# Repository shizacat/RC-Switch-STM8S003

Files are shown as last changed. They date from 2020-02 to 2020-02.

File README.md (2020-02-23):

# Description

Reacts to switching the joystick stick switch.

## Principle of work

The input receives a PWM signal from an RC receiver. For different stick positions there will be different duty cycle. By measuring its duration, you can determine the position of the stick and send a signal to the MC output.

# Hardware

Since my option was needed to turn on the LED backlight, I do not use external power and a powerful transistor. I also needed only one position.

# Firwmware

SDCC is used for compilation. You also need STM8S_SPL from ST - a library for working with peripherals.

## How to flash

I use stm8flash for flash.

First of all, you need to configure Option bytes for hardware. For capturing, the 1st channel of the 1st timer is used (Channel 1 TIM1).

```bash
echo -ne '\x00\x00\xff\x01\xfe\x00\xff\x00\xff\x00\xff' > opt.bin
stm8flash -c stlinkv2 -p stm8s103f3 -s opt -w opt.bin
```

This line activates alternative functions of the leg we need: Port C5 alternate function = TIM2_CH1; port C6 alternate function =TIM1_CH1; port C7 alternate function = TIM1_CH2.

Then we are already flashing the firmware itself (firmware.bin). Here you can already use: make upload, or manually download stm8flash.

```bash
./stm8flash -c stlinkv2 -p stm8s003f3 -w firmware.ihx
```

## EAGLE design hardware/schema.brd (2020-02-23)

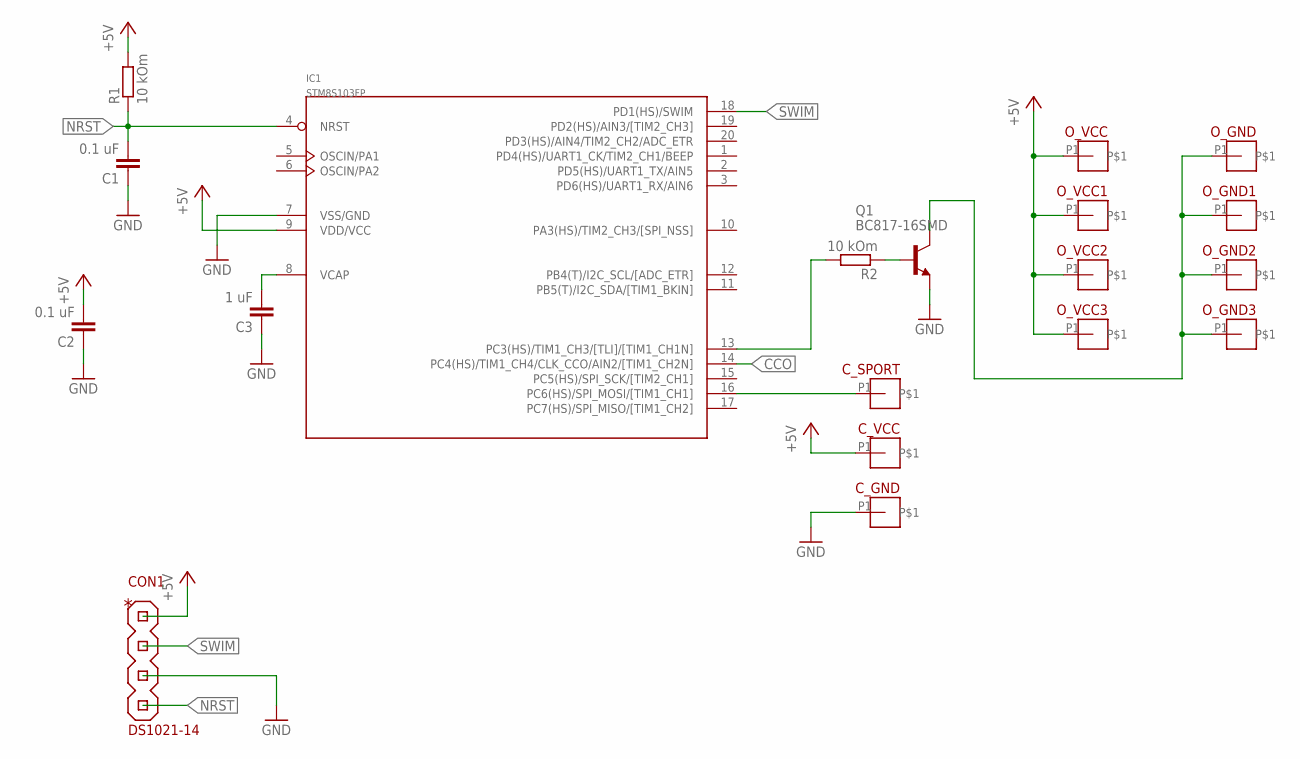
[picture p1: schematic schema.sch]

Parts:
C1, C2: 0.1 uF; C0603
C3: 1 uF; C0603
CON1: DS1021-14; DS1021-1*4
C_GND: PAD1_0.8
C_SPORT: PAD1_0.8
C_VCC: PAD1_0.8
IC1: STM8S103FP; TSSOP20
O_GND, O_GND1, O_GND2, O_GND3: PAD1_0.8
O_VCC, O_VCC1, O_VCC2, O_VCC3: PAD1_0.8
Q1: BC817-16SMD; SOT23-BEC
R1, R2: 10 kOm; R0603

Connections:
+5V: C2.2, CON1.P1, C_VCC.P1, IC1.9 (VDD/VCC), O_VCC.P1, O_VCC1.P1, O_VCC2.P1, O_VCC3.P1, R1.2
CCO: IC1.14 (PC4(HS)/TIM1_CH4/CLK_CCO/AIN2/[TIM1_CH2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)
GND: C1.1, C2.1, C3.1, CON1.P3, C_GND.P1, IC1.7 (VSS/GND), Q1.E
unnamed: C_SPORT.P1, IC1.16 (PC6(HS)/SPI_MOSI/[TIM1_CH1])
unnamed: C3.2, IC1.8 (VCAP)
unnamed: O_GND.P1, O_GND1.P1, O_GND2.P1, O_GND3.P1, Q1.C
unnamed: IC1.13 (PC3(HS)/TIM1_CH3/[TLI]/[TIM1_CH1N]), R2.2
unnamed: Q1.B, R2.1
NRST: C1.2, CON1.P4, IC1.4 (NRST), R1.1
SWIM: CON1.P2, IC1.18 (PD1(HS)/SWIM)

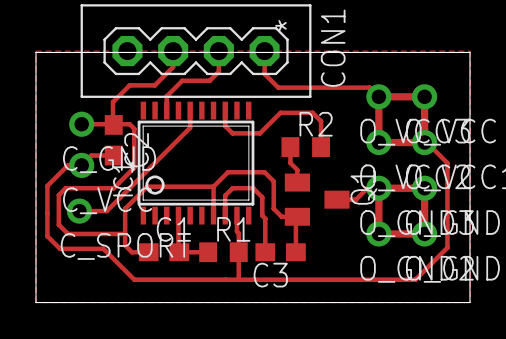
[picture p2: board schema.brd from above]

Board: 2 copper layers, 24.1 x 13.9 mm, 19 parts (0 on the bottom side), 9 nets.

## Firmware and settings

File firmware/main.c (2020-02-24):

/**
  ******************************************************************************
  * @file     RC-Switch\main.c
  * @author   
  * @version  
  * @date     
  * @brief    
  ******************************************************************************
  * @attention
  *
  ******************************************************************************
  */ 

/* Includes ------------------------------------------------------------------*/
#include "stm8s.h"

/* Private typedef -----------------------------------------------------------*/
/* Private define ------------------------------------------------------------*/
/* Private macro -------------------------------------------------------------*/
/* Private variables ---------------------------------------------------------*/
uint16_t ICValue1 =0, ICValue2 =0;
uint8_t state =0;

/* Private function prototypes -----------------------------------------------*/
static void TIM1_Config(void);
static void GPIO_Config(void);
static void CLK_Config(void);

/* Private functions ---------------------------------------------------------*/
/* Public functions ----------------------------------------------------------*/

/**
  * @brief  Main program.
  * @param  None
  * @retval None
  */
void main(void)
{

  /* GPIO CONFIG ----------------------------------------------- */
  GPIO_Config();

  CLK_Config();

  /* TIM1 configuration -----------------------------------------*/
  TIM1_Config();
    
  /* Insert a break point here */
  while (1)
  {
    if (TIM1_GetFlagStatus(TIM1_FLAG_CC1) == SET) {
      if(state == FALSE)          {
          ICValue1 = TIM1_GetCapture1();
          TIM1_ICInit(
            TIM1_CHANNEL_1, TIM1_ICPOLARITY_FALLING, TIM1_ICSELECTION_DIRECTTI,
            TIM1_ICPSC_DIV1, 0x0
          );
      }
      else {
          ICValue2 = TIM1_GetCapture1();
          TIM1_ICInit(
            TIM1_CHANNEL_1, TIM1_ICPOLARITY_RISING, TIM1_ICSELECTION_DIRECTTI,
            TIM1_ICPSC_DIV1, 0x0
          );
          // Check threshold
          if ((ICValue2 - ICValue1) >= 80) {
            GPIO_WriteHigh(GPIOC, GPIO_PIN_3);
          } else {
            GPIO_WriteLow(GPIOC, GPIO_PIN_3);
          };
      }
      state = ~state;
      TIM1_ClearFlag(TIM1_FLAG_CC1);
    }
  }
}

/**
  * @brief  Configure ports
  * @param  None
  * @retval None
  */
static void GPIO_Config(void){
  /* Connect LSI to COO pin*/
  GPIO_Init(GPIOC, GPIO_PIN_4, GPIO_MODE_OUT_PP_LOW_FAST);
  CLK_CCOConfig(CLK_OUTPUT_LSI);
  CLK_CCOCmd(ENABLE);

  // Pin to transistor key
  GPIO_Init(GPIOC, GPIO_PIN_3, GPIO_MODE_OUT_PP_LOW_FAST);
  // Pin input signal
  // GPIO_Init(GPIOC, GPIO_PIN_6, GPIO_MODE_IN_PU_NO_IT);
}

/**
  * @brief  Switch to LSI as system clock source.
            System clock prescaler: 1
  * @param  None
  * @retval None
  */
static void CLK_Config(void){
  // CLK_DeInit();

  CLK_LSICmd(ENABLE);
  CLK_SYSCLKConfig(CLK_PRESCALER_CPUDIV1);
  CLK_ClockSwitchConfig(
    CLK_SWITCHMODE_AUTO,
    CLK_SOURCE_LSI, 
    DISABLE,
    CLK_CURRENTCLOCKSTATE_DISABLE
  );

  // Configure periphery
  CLK_PeripheralClockConfig(CLK_PERIPHERAL_I2C, DISABLE);
  CLK_PeripheralClockConfig(CLK_PERIPHERAL_SPI, DISABLE);
  CLK_PeripheralClockConfig(CLK_PERIPHERAL_UART1, DISABLE);
  CLK_PeripheralClockConfig(CLK_PERIPHERAL_UART2, DISABLE);
  CLK_PeripheralClockConfig(CLK_PERIPHERAL_TIMER4, DISABLE);
  CLK_PeripheralClockConfig(CLK_PERIPHERAL_TIMER2, DISABLE);
  CLK_PeripheralClockConfig(CLK_PERIPHERAL_TIMER3, DISABLE);
  CLK_PeripheralClockConfig(CLK_PERIPHERAL_AWU, DISABLE);
  CLK_PeripheralClockConfig(CLK_PERIPHERAL_ADC, DISABLE);
  CLK_PeripheralClockConfig(CLK_PERIPHERAL_CAN, DISABLE);

  CLK_PeripheralClockConfig(CLK_PERIPHERAL_TIMER1, ENABLE);
}

/**
  * @brief  Configure TIM1 to to capture the internal clock source (LSI)
  * @param  None
  * @retval None
  */
static void TIM1_Config(void)
{
  TIM1_DeInit();

  TIM1_TimeBaseInit(27, TIM1_COUNTERMODE_UP, 0xFFFF, 0);
  TIM1_ICInit(
    TIM1_CHANNEL_1, TIM1_ICPOLARITY_FALLING, TIM1_ICSELECTION_DIRECTTI,
    TIM1_ICPSC_DIV1, 0x0
  );
  
  // Enable TIM1
  TIM1_Cmd(ENABLE);
}

#ifdef USE_FULL_ASSERT

/**
  * @brief  Reports the name of the source file and the source line number
  *   where the assert_param error has occurred.
  * @param file: pointer to the source file name
  * @param line: assert_param error line source number
  * @retval None
  */
void assert_failed(uint8_t* file, uint32_t line)
{ 
  /* User can add his own implementation to report the file name and line number,
     ex: printf("Wrong parameters value: file %s on line %d\r\n", file, line) */

  /* Infinite loop */
  while (1)
  {
  }
}
#endif

/************************ END OF FILE ****/

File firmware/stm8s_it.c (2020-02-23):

/**
  ******************************************************************************
  * @file     stm8s_it.c
  * @author   MCD Application Team
  * @version  V2.2.0
  * @date     30-September-2014
  * @brief    Main Interrupt Service Routines.
  ******************************************************************************
  * @attention
  *
  * <h2><center>&copy; COPYRIGHT 2014 STMicroelectronics</center></h2>
  *
  * Licensed under MCD-ST Liberty SW License Agreement V2, (the "License");
  * You may not use this file except in compliance with the License.
  * You may obtain a copy of the License at:
  *
  *        http://www.st.com/software_license_agreement_liberty_v2
  *
  * Unless required by applicable law or agreed to in writing, software 
  * distributed under the License is distributed on an "AS IS" BASIS, 
  * WITHOUT WARRANTIES OR CONDITIONS OF ANY KIND, either express or implied.
  * See the License for the specific language governing permissions and
  * limitations under the License.
  *
  ******************************************************************************
  */ 

/* Includes ------------------------------------------------------------------*/
#include "stm8s_it.h"

/* Private typedef -----------------------------------------------------------*/
/* Private define ------------------------------------------------------------*/
/* Private macro -------------------------------------------------------------*/
/* Private variables ---------------------------------------------------------*/
/* Private function prototypes -----------------------------------------------*/
/* Private functions ---------------------------------------------------------*/

/* Public functions ----------------------------------------------------------*/

/** @addtogroup TIM1_Input_Capture
  * @{
  */
#ifdef _COSMIC_
/**
  * @brief  Dummy interrupt routine
  * @param  None
  * @retval None
  */
INTERRUPT_HANDLER(NonHandledInterrupt, 25)
{
  /* In order to detect unexpected events during development,
     it is recommended to set a breakpoint on the following instruction.
  */
}
#endif /*_COSMIC_*/

/**
  * @brief  TRAP interrupt routine
  * @param  None
  * @retval None
  */
#if !defined(_SDCC_) || (SKIP_TRAPS!=1)    // SDCC patch: trap handling requires SDCC >=v3.4.3
INTERRUPT_HANDLER_TRAP(TRAP_IRQHandler)
{
  /* In order to detect unexpected events during development,
     it is recommended to set a breakpoint on the following instruction.
  */
}
#endif

/**
  * @brief  Top Level Interrupt routine
  * @param  None
  * @retval None
  */
INTERRUPT_HANDLER(TLI_IRQHandler, 0)
{
  /* In order to detect unexpected events during development,
     it is recommended to set a breakpoint on the following instruction.
  */
}

/**
  * @brief  Auto Wake Up Interrupt routine
  * @param  None
  * @retval None
  */
INTERRUPT_HANDLER(AWU_IRQHandler, 1)
{
  /* In order to detect unexpected events during development,
     it is recommended to set a breakpoint on the following instruction.
  */
}

/**
  * @brief  Clock Controller Interrupt routine
  * @param  None
  * @retval None
  */
INTERRUPT_HANDLER(CLK_IRQHandler, 2)
{
  /* In order to detect unexpected events during development,
     it is recommended to set a breakpoint on the following instruction.
  */
}

/**
  * @brief  External Interrupt PORTA Interrupt routine
  * @param  None
  * @retval None
  */
INTERRUPT_HANDLER(EXTI_PORTA_IRQHandler, 3)
{
  /* In order to detect unexpected events during development,
     it is recommended to set a breakpoint on the following instruction.
  */
}

/**
  * @brief  External Interrupt PORTB Interrupt routine
  * @param  None
  * @retval None
  */
INTERRUPT_HANDLER(EXTI_PORTB_IRQHandler, 4)
{
  /* In order to detect unexpected events during development,
     it is recommended to set a breakpoint on the following instruction.
  */
}

/**
  * @brief  External Interrupt PORTC Interrupt routine
  * @param  None
  * @retval None
  */
INTERRUPT_HANDLER(EXTI_PORTC_IRQHandler, 5)
{
  /* In order to detect unexpected events during development,
     it is recommended to set a breakpoint on the following instruction.
  */
}

/**
  * @brief  External Interrupt PORTD Interrupt routine
  * @param  None
  * @retval None
  */
INTERRUPT_HANDLER(EXTI_PORTD_IRQHandler, 6)
{
  /* In order to detect unexpected events during development,
     it is recommended to set a breakpoint on the following instruction.
  */
}

/**
  * @brief  External Interrupt PORTE Interrupt routine
  * @param  None
  * @retval None
  */
INTERRUPT_HANDLER(EXTI_PORTE_IRQHandler, 7)
{
  /* In order to detect unexpected events during development,
     it is recommended to set a breakpoint on the following instruction.
  */
}
#ifdef STM8S903
/**
  * @brief  External Interrupt PORTF Interrupt routine
  * @param  None
  * @retval None
  */
 INTERRUPT_HANDLER(EXTI_PORTF_IRQHandler, 8)
{
  /* In order to detect unexpected events during development,
     it is recommended to set a breakpoint on the following instruction.
  */
}
#endif /*STM8S903*/

#if defined (STM8S208) || defined (STM8AF52Ax)
/**
  * @brief CAN RX Interrupt routine.
  * @param  None
  * @retval None
  */
 INTERRUPT_HANDLER(CAN_RX_IRQHandler, 8)
{
  /* In order to detect unexpected events during development,
     it is recommended to set a breakpoint on the following instruction.
  */
}

/**
  * @brief  CAN TX Interrupt routine
  * @param  None
  * @retval None
  */
 INTERRUPT_HANDLER(CAN_TX_IRQHandler, 9)
{
  /* In order to detect unexpected events during development,
     it is recommended to set a breakpoint on the following instruction.
  */
}
#endif /*STM8S208 || STM8AF52Ax */

/**
  * @brief  SPI Interrupt routine
  * @param  None
  * @retval None
  */
INTERRUPT_HANDLER(SPI_IRQHandler, 10)
{
  /* In order to detect unexpected events during development,
     it is recommended to set a breakpoint on the following instruction.
  */
}

/**
  * @brief  Timer1 Update/Overflow/Trigger/Break Interrupt routine
  * @param  None
  * @retval None
  */
INTERRUPT_HANDLER(TIM1_UPD_OVF_TRG_BRK_IRQHandler, 11)
{
  /* In order to detect unexpected events during development,
     it is recommended to set a breakpoint on the following instruction.
  */
}

/**
  * @brief  Timer1 Capture/Compare Interrupt routine
  * @param  None
  * @retval None
  */
INTERRUPT_HANDLER(TIM1_CAP_COM_IRQHandler, 12)
{
  /* In order to detect unexpected events during development,
     it is recommended to set a breakpoint on the following instruction.
  */
}

#ifdef STM8S903
/**
  * @brief  Timer5 Update/Overflow/Break/Trigger Interrupt routine
  * @param  None
  * @retval None
  */
 INTERRUPT_HANDLER(TIM5_UPD_OVF_BRK_TRG_IRQHandler, 13)
{
  /* In order to detect unexpected events during development,
     it is recommended to set a breakpoint on the following instruction.
  */
}
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

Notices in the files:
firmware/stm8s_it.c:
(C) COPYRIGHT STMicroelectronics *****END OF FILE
